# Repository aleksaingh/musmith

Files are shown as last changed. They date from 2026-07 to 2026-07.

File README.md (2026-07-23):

# MuSmith
MuSmith is like a mini music controller that obviously can control music (previous track, pause/play, next track) it also has a rotary encoder and an oled screen. For the buttons it has mechanical switches.

## Difficulties
For the difficulties i was pretty much the same as my last project [Clicksmith](https://github.com/aleksaingh/clicksmith). The case in Fusion 360 was really messing with me, I spent a good time with designing it.

## Features:
  + Fully 3D printed case
  + 3 Keys
  + A rotary encoder
  + And a 0.91" oled screen
## Firmware
The firmware is a custom circuitpython script (That I and AI made) and a janky Powershell script (This one AI made) that runs at startup. Why? Because i couldn't think of a better way to capture the song and the artist to display on the OLED. The rotary encoder controls the volume and the keys as said in the begining go to the previous track - play/pause - go to the next track.

## OLED screen
As i said the oled is a 0.91" screen that displays the current song and the artist. If i really want it i will maybe add the current time and the progress bar also.

## BOM
What's needed to make this
  + 1x case (2 3D printed parts)
  + 4x M3x5x4 heatset inserts
  + 4x M3x16 screws
  + 3x Cherry MX Switches
  + 3x Cherry DSA keycaps
  + 1x EC11 Rotary encoder
  + 1x XIAO RP2040
  + 1x 0.91" OLED

That's All! 👋

# Images and other nerdy stuff

## CAD

Case was made in Fusion 360.

The top and bottom halves of the case fit together using four heatset inserts and four M3 Screws.

Fusion360_EEurYrP4EO

## PCB

The PCB was made in KiCad pretty fast.

kicad_DkRULZKsaH

## Schematic

Fusion360_sgYUJH9XTz

## Credits
Thank you [DinoMito1](https://github.com/DinoMito1) for giving me inpso for the readme (some parts i stole and changed but we don't talk about that)

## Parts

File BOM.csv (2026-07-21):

Item | Quantity | Description
Case | 1 | 3D printed case (2 parts)
Heatset Inserts | 4 | M3x5x4 heatset inserts
Screws | 4 | M3x16 screws
Mechanical Switches | 3 | Cherry MX Switches
Keycaps | 3 | Cherry DSA keycaps
Rotary Encoder | 1 | EC11 Rotary encoder
Microcontroller | 1 | XIAO RP2040
OLED Display | 1 | 0.91" OLED screen

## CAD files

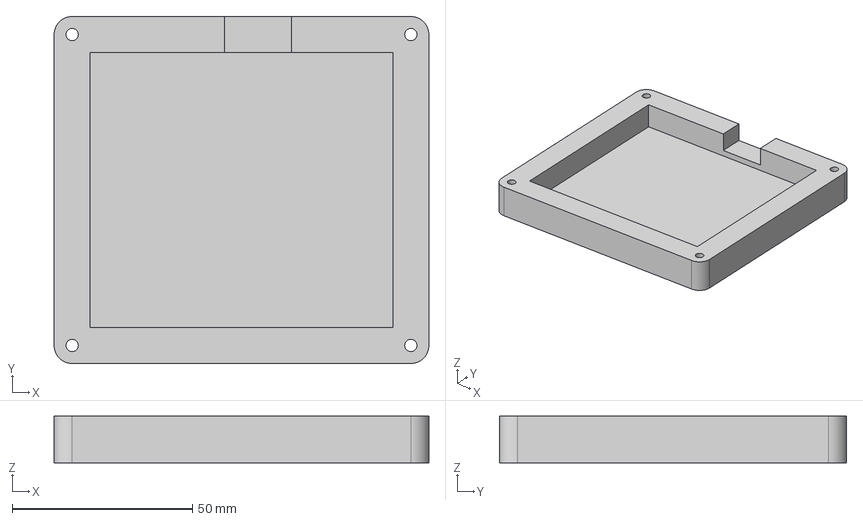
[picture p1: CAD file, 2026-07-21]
CAD/MuSmithBase.step
103.9 x 96.2 x 13.0 mm

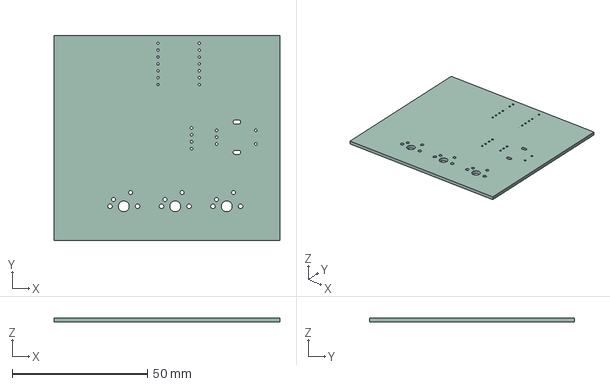
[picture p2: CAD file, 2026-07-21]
PCB/musmith.step
83.4 x 75.7 x 1.51 mm

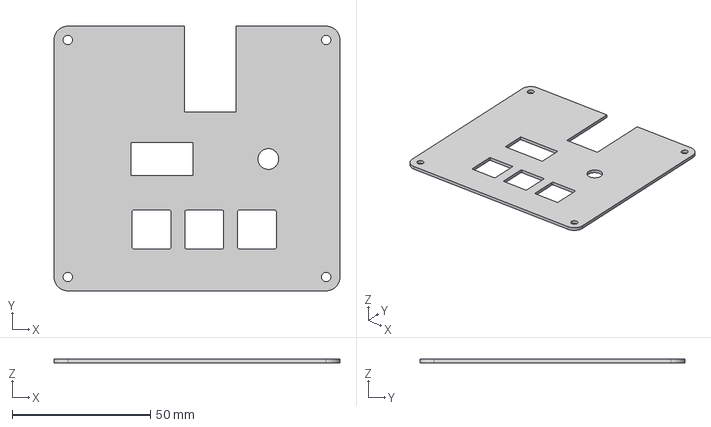
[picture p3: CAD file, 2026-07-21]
CAD/MuSmithTop.step
103.4 x 95.7 x 1.50 mm

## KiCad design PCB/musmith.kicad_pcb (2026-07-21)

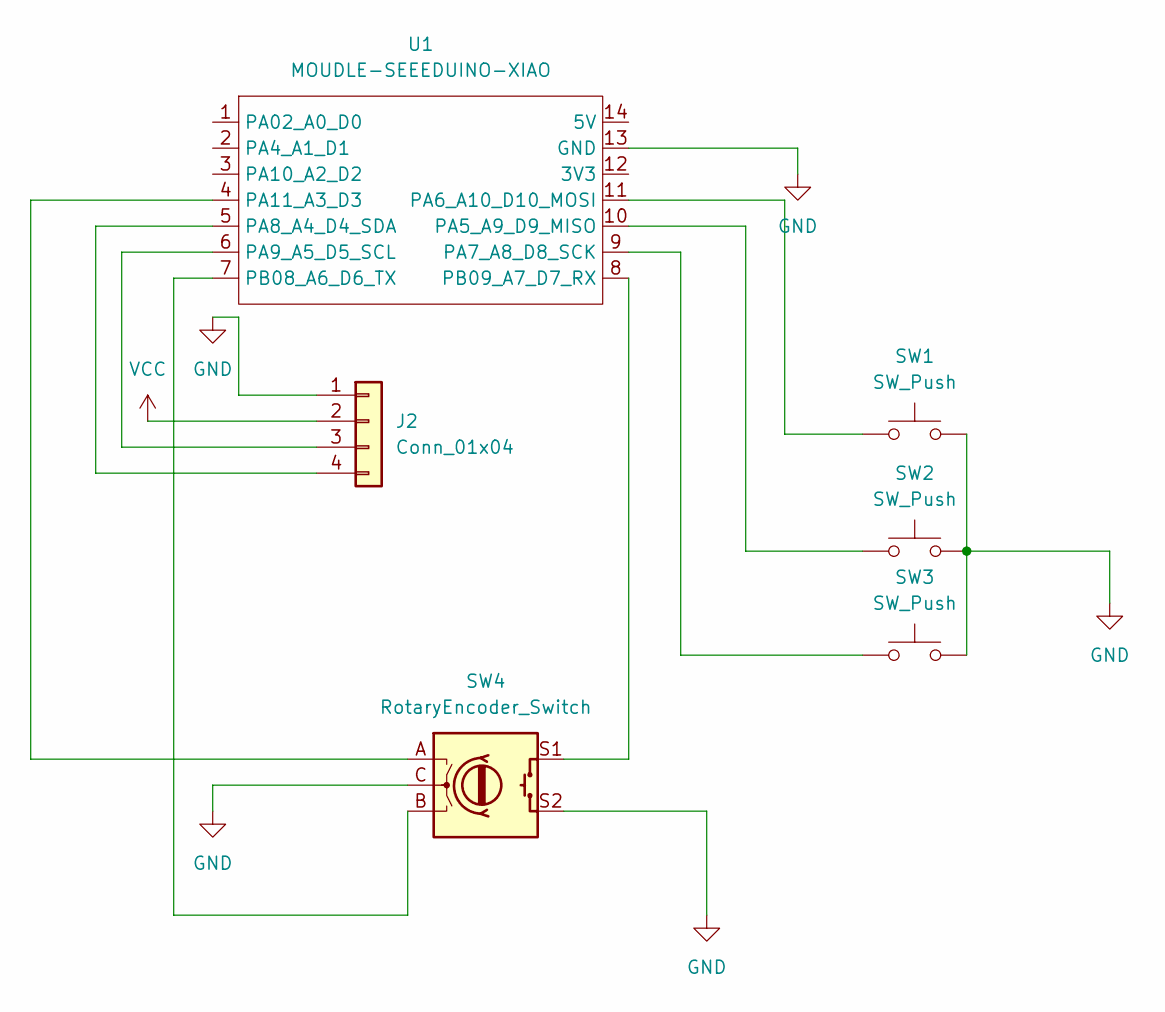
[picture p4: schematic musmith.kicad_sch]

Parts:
J2: Conn_01x04; SSD1306-0.91-OLED-4pin-128x32
SW1, SW2, SW3: SW_Push; SW_Cherry_MX_1.00u_PCB
SW4: RotaryEncoder_Switch; RotaryEncoder_Alps_EC11E-Switch_Vertical_H20mm
U1: MOUDLE-SEEEDUINO-XIAO; XIAO-RP2040-DIP

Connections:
GND: J2.1, SW1.2, SW2.2, SW3.2, SW4.C, SW4.S2, U1.13 (GND)
unnamed: J2.3, U1.6 (PA9_A5_D5_SCL)
unnamed: J2.4, U1.5 (PA8_A4_D4_SDA)
unnamed: SW2.1, U1.10 (PA5_A9_D9_MISO)
unnamed: SW1.1, U1.11 (PA6_A10_D10_MOSI)
unnamed: SW3.1, U1.9 (PA7_A8_D8_SCK)
unnamed: SW4.A, U1.4 (PA11_A3_D3)
unnamed: SW4.B, U1.7 (PB08_A6_D6_TX)
unnamed: SW4.S1, U1.8 (PB09_A7_D7_RX)
VCC: J2.2

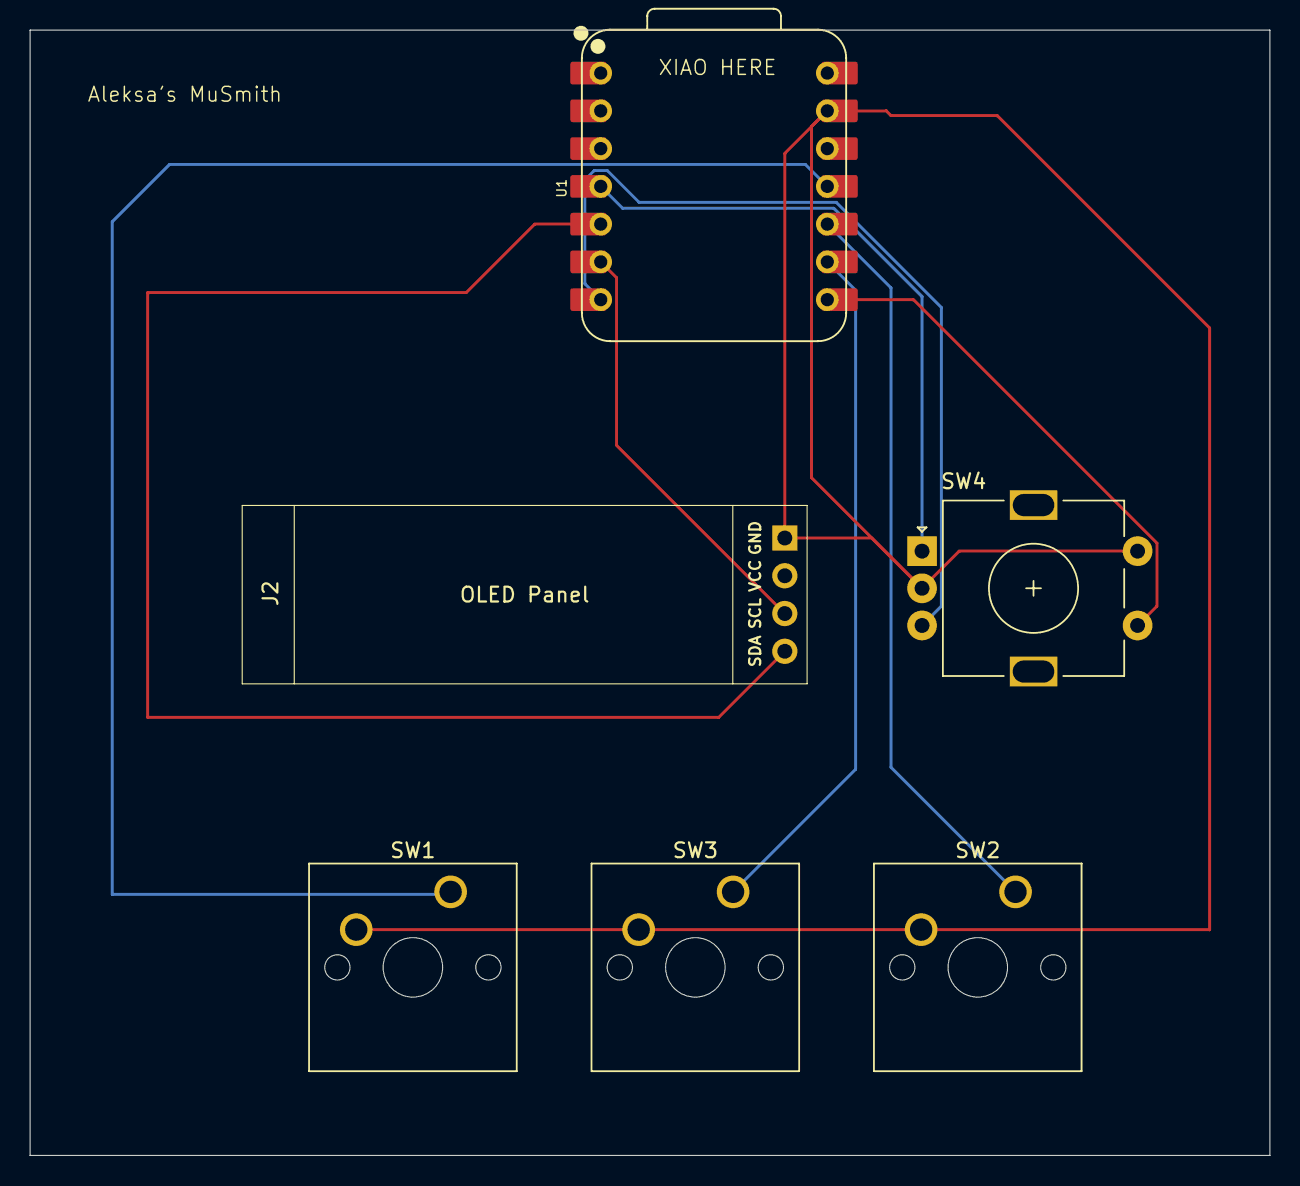
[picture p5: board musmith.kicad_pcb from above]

Board: 2 copper layers, 83.4 x 75.7 mm, 6 parts (0 on the bottom side), 9 nets.

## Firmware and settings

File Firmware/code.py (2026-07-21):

import time
import board
import digitalio
import usb_hid
from adafruit_hid.consumer_control import ConsumerControl
from adafruit_hid.consumer_control_code import ConsumerControlCode
import displayio
import terminalio
from adafruit_display_text import label
import adafruit_displayio_ssd1306
import rotaryio

displayio.release_displays()
i2c = board.I2C()
display_bus = displayio.I2CDisplay(i2c, device_address=0x3C)

splash = displayio.Group()
display.root_group = splash

text_area = label.Label(terminalio.FONT, text="Ready", color=0xFFFF00, x=10, y=30)
splash.append(text_area)

encoder = rotaryio.IncrementalEncoder(board.D3, board.D6)
last_encoder_position = encoder.position

cc = ConsumerControl(usb_hid.devices)

button_config = [
    {
        "pin": board.D7,
        "code": ConsumerControlCode.SCAN_PREVIOUS_TRACK,
        "name": "Previous Track",
    },
    {
        "pin": board.D10,
        "code": ConsumerControlCode.PLAY_PAUSE,
        "name": "Play/Pause",
    },
    {
        "pin": board.A0,
        "code": ConsumerControlCode.SCAN_NEXT_TRACK,
        "name": "Next Track",
    },
]

buttons = []
last_states = []

for config in button_config:
    button = digitalio.DigitalInOut(config["pin"])
    button.direction = digitalio.Direction.INPUT
    button.pull = digitalio.Pull.UP
    buttons.append(button)
    last_states.append(button.value)

print("Ready to control media playback. Press buttons to send commands.")
# 1. buttons
while True:
    for i, button in enumerate(buttons):
        current_state = button.value
        if current_state != last_states[i]:
            if not current_state:
                cc.send(button_config[i]["code"])
                print(f"Sent command: {button_config[i]['name']}")
            last_states[i] = current_state
    time.sleep(0.01)
# 2. rotary encoder
    current_encoder_position = encoder.position
    if current_encoder_position != last_encoder_position:
        if current_encoder_position > last_encoder_position:
            cc.send(ConsumerControlCode.VOLUME_INCREMENT)
            print("Volume Up")
        else:
            cc.send(ConsumerControlCode.VOLUME_DECREMENT)
            print("Volume Down")
        last_encoder_position = current_encoder_position
